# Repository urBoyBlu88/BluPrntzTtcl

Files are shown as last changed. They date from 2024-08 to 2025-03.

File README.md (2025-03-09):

Check out the new Better Reticles code!

keep in mind, the ESP32 is directley connected to the pins of the LCD
The tft settings will have to be edited to match your wiring!
remeber all you need to change is 

CS = 
DC = 
RES =

and then in the setup:
SPI.begin(SDA,MISO,SCL,CS)

after changing those things to match your connections you should be golden :) 

//////////////////////////////////////////////////////////////
Plug into your computer USB 3.0 - must be a usb3.0 port

Your ESP32 C3 will not connect to your Computer Immediatley you MUST PUT IT INTO BOOT MODE!

HOW TO PUT INTO BOOT MODE

Hold the RESET button, then press the BOOT button, now both button held down; let go of Reset and then after 1 more second let go of Boot and you should connect.

Download the Code Zip folder

unzip that folder

run the .ino file

it will ask you to make a new folder for it

hit yes/ok

now select your board - set it to a esp32 c3 dev module

upload

////IMPORTANT/////

-IF your ESP32 C3 will not connect to your Computer, hold the RESET button, and push the BOOT down at the same time, let go of Reset and then let go of Boot after another second and you should connect.

/////////////////1/24/25 UPDATE/////////////////////

Check out the new XiaoSeedStudioFossDot file if you want to only have a single port for charging and programming! or you accidently got a seed studio esp32c3!

//////////////////OLED v2 UGLY////////////////////////////////////

COMPONENTS
1.	ESP32-C3 with 0.42 OLED
a.	Link for product
2.	Lipo Battery Rechargeable Lithium Polymer ion Battery 
a.	I like to buy the gas station disposable vapes, and steal the battery out of it
3.	Switch 3 prong
4.	Button – button cap
5.	Flash light led and reflector
6.	Battery Charging Board with Battery Protection BMS 5V Micro USB 1A 186 50 Charge Module
7.	Connection wires

3D PRINTING STUFF
1.	Elagoo PLA+
2.	Top half –
 
3.	Rail Connection base left side clamp –
 
4.	right side clamp –

HARDWARE
1.	4  m2 screws
2.	2 bolts and nuts m4
3.	USBC cable 
4.	Botton cap – you can print this too

SOFTWARE
1.	Arduino IDE
a.	Libraries for ESP32-C3 dev module
b.	U8g2lib
2.	https://lopaka.app/ - this is to make graphics 
3.	Slicer software

STEP ONE: PRINT IT
Bring the STL files into your preferred slicer program, I Used Anycubic Slicer as I have a Anycubic Kobra 3 printer. 

My Print Setting:
60 to 100% infill – this is up to you, more infill = more durability. 
Normal PLA+ settings for your printer
I use organic supports from build plate only
Print orientation 
-leave it as it is in the STL it should be in the proper rotation see images for reference. You can change the base/rail connection orientation, as I have not yet found the best one. 

STEP TWO: ASSEMBLY
I like to place my components in the frame without securing them. 

From here I measure my wires to cut proper lengths and so as not to have too much wire inside. 

Follow this Diagram  

Rechargeable battery :
Solder the batter + to recharge board bat+

Solder battery – to recharge board bat-

Battery power to ESP32-C3:
Solder wire to out + on the recharge board 

Solder the other side of that wire to the left side of the Switch
Solder a wire to the middle prong of the Switch
The other side of the middle prong wire, Solder to the BAT pin on the esp32 

Solder wire to the Out- on the recharge board

Solder a black wire onto the Grnd Pin on the Esp32. This is so we can add multiple connections to the grnd pin. 

Slice the black wire so you have 3 open connection points

Solder the other side of that wire to the black grnd wire at the connection point closest to the ESP32

Now it’s a rechargeable battery powered esp32!

Lets Add a button and a Flashlight!
First lets add a wire coming off the 3V pin on the ESP32. This will allow for multiple connection points.

Next, solder a 10kOhm resistor to one pin on your button. 
Solder a wire to the other side of the resistor.
Solder the other side of the resistor wire to the second connection on the ground wire. 
Solder a wire on the same button pin as the resistor
solder that wire to pin 1 on the ESP 32
Now, the pin diagonally across from the button pin the resistor and wire are connected to…
Solder a red wire
Connect the other side of the red wire to one connection point of the 3.3V pin
Voila you have a button on a rechargeable Esp32 c3

If you want a flashlight follow this, if not skip ahead to the next section.
Flashlight;
This one about the same as the button. If you don’t have a flashlight light with a little board connected to it, just add a 10kohm resistor to your led + leg
Connect a red wire to the + pin, usually the one in the middle of the board
Connect the other side to a connection point of the Pin 7
Now connect the – pin of the led to a black wire, usually the post on a board or the outside circle.
Connect the other side to a connection point on the ground wire on the esp32.
Now you have a flashlight that will be able to be toggled on and off via Bluetooth

All right that’s everything Time to Code!

/////////////////////////////////////FOSS DOT RGB/////////////////////////////////////////////////////
FOSS DOT Optics Operation
 
Hi there!
Thank you for joining the Blue Printz Tactical Family!
As the new owner of a FOSS Dot Optic I wanted to give you some basic instructions!
Charging: remove the slip on ring on the back. Once removed, you can now lift out the main carriage, make sure to line the battery back up with it slot when reinserting! On the exposed bottom of the carriage are 2 usb ports, one on the blue board and one on the black esp32. Connect to the blue tp4056 to charge, if you so desire to reprogram, plug in to the esp32 and inser the usb cabe to your computer. 

Reprogram:
I used Arduino IDE so it should be easy enough for you as well. 
https://github.com/urBoyBlu88/BluPrntzTtcl/blob/main/ColorFOSSDOT.ino

Here is the code, id recommend swapping the images that are green. Blue and white images work best in all light conditions. I’m still testing other color configures.
You can download my image .h files from this same git repo.

download this board manager, same version is probably best.

and the adafruit st7735 and st7789 lib

the correct board to select is esp32 c3 dev board
 
here is my upload config

Bluetooth Windage and Elevation:
On your phone, Download this app,

https://play.google.com/store/apps/details?id=com.zhctwh.ble_tester 
With your Foss Dot powered ON. Bluetooth on you phone turned ON, and location on your phone turned ON; open the app and hit the scan button at the bottom. Search for “UglyOptic” and select it. 
Then click the last option on the list that says “service” and has a bunch of letters and numbers.

Next tap in the write area to enter text. Set the check box from hex -> ASCII. You want it to be ASCII.

Here are your codes to enter for W&E(I hope they are as simple as I think they are!)
!* all entered letter should be lowercase *!
l – enter lowercase ‘L’, your reticle should shift left 
r – enter lowercase ‘R’, your reticle should shift right
u – enter lowercase ‘U’, your reticle should shift up
d – enter lowercase ‘D’, your reticle should move down
m – enter lowercase ‘M’ your reticle should center on screen. 

Lenses are removable if you wish to change the view of the reticle on the lens. OR simply if you need to replace the lens. Here is the lens used: lens.

If you have any questions or concerns at all, please do not hesitate to reach out! We are always happy to help however we can here at Blue Printz Tactical!
Thanks for your Support!
Check back on the site or on reddit for new updates and innovations!
Warm Regards,
Blue Printz Tactical
blooperspecive@gmail.com

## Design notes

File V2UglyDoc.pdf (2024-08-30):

# V2-UGLY

### COMPONENTS

1. ESP32-C3 with 0.42 OLED
a. Link for product
2. Lipo Battery Rechargeable Lithium Polymer ion Battery Pack
a. I like to buy the gas station disposable vapes, and steal the battery out of it
b. Or, link
3. Switch 3 prong
4. Button – button cap
5. Flash light led and reflector
6. Battery Charging Board with Battery Protection BMS 5V Micro USB 1A 186 50 Charge Module (https://www.amazon.com/Mudder-Pieces-Charging-Battery-Protection/dp/B087Q915LF)
7. Connection wires

### 3D PRINTING STUFF

1. Elagoo PLA+
2. Top half –
3. Rail Connection base left side clamp –
4. right side clamp -

### HARDWARE

1. 4 m2 screws
2. 2 bolts and nuts m4
3. USBC cable
4. Botton cap – you can print this too

### SOFTWARE

1. Arduino IDE
a. Libraries for ESP32-C3 dev module
b. U8g2lib
2. https://lopaka.app/ - this is to make graphics
3. Slicer software

# V2-UGLY

### STEP ONE: PRINT IT

Bring the STL files into your preferred slicer program, I Used Anycubic Slicer as I have a Anycubic Kobra 3 printer.

My Print Setting:
60 to 100% infill – this is up to you, more infill = more durability. Normal PLA+ settings for your printer
I use organic supports from build plate only
Print orientation
-leave it as it is in the STL it should be in the proper rotation see images for reference.

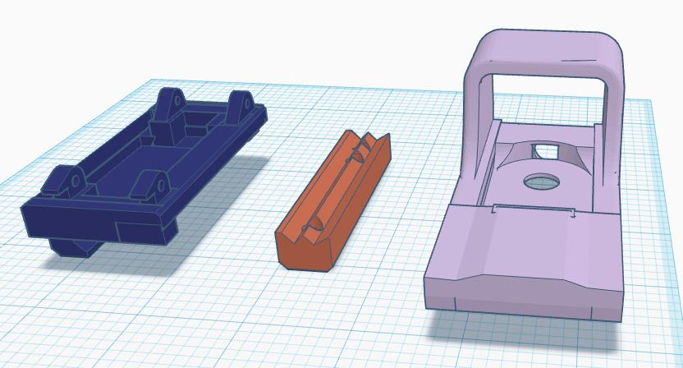
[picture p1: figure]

### STEP TWO: ASSEMBLY

I like to place my components in the frame without securing them.

From here I measure my wires to cut proper lengths and so as not to have too much wire inside.

# V2-UGLY

Follow this Diagram

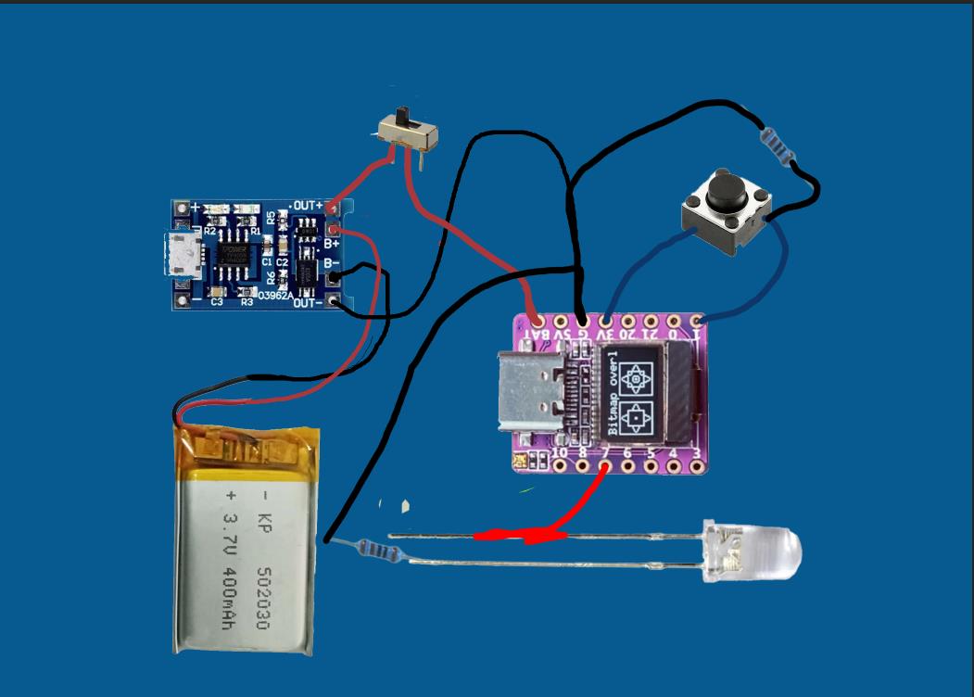
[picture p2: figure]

Rechargeable battery :
Solder the batter + to recharge board bat+

Solder battery – to recharge board bat-

Battery power to ESP32-C3:
Solder wire to out + on the recharge board

Solder the other side of that wire to the left side of the Switch
Solder a wire to the middle prong of the Switch
The other side of the middle prong wire, Solder to the BAT pin on the esp32

# V2-UGLY

Solder wire to the Out- on the recharge board

Solder a black wire onto the Grnd Pin on the Esp32. This is so we can add multiple connections to the grnd pin.

Slice the black wire so you have 3 open connection points

Solder the other side of that wire to the black grnd wire at the connection point closest to the ESP32

Now it’s a rechargeable battery powered esp32!

Lets Add a button and a Flashlight!
First lets add a wire coming off the 3V pin on the ESP32. This will allow for multiple connection points.

Next, solder a 10kOhm resistor to one pin on your button.
Solder a wire to the other side of the resistor.
Solder the other side of the resistor wire to the second connection on the ground wire. Solder a wire on the same button pin as the resistor
solder that wire to pin 1 on the ESP 32
Now, the pin diagonally across from the button pin the resistor and wire are connected to… Solder a red wire
Connect the other side of the red wire to one connection point of the 3.3V pin
Voila you have a button on a rechargeable Esp32 c3

If you want a flashlight follow this, if not skip ahead to the next section. Flashlight;

# V2-UGLY

This one about the same as the button. If you don’t have a flashlight light with a little board connected to it, just add a 10kohm resistor to your led + leg
Connect a red wire to the + pin, usually the one in the middle of the board
Connect the other side to a connection point of the Pin 7
Now connect the – pin of the led to a black wire, usually the post on a board or the outside circle. Connect the other side to a connection point on the ground wire on the esp32.
Now you have a flashlight that will be able to be toggled on and off via Bluetooth

All right that’s everything Time to Code!

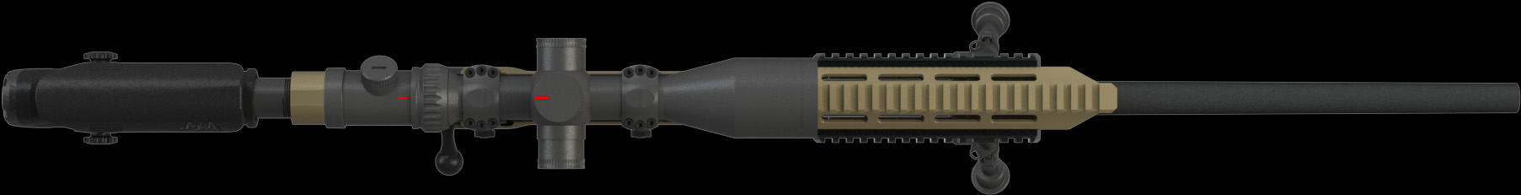
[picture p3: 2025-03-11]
3DViewerFiles/playerRifle.jpg

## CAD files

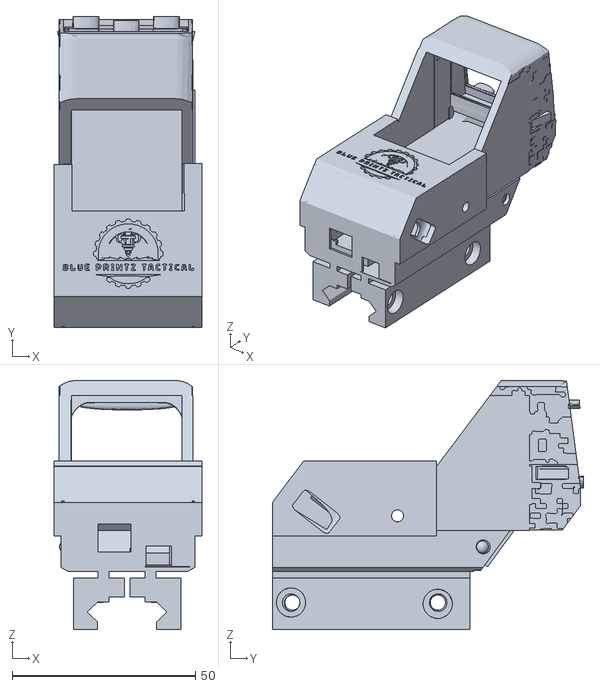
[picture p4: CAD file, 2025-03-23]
3DViewerFiles/FullBuild.stl
40.3 x 84.9 x 67.9

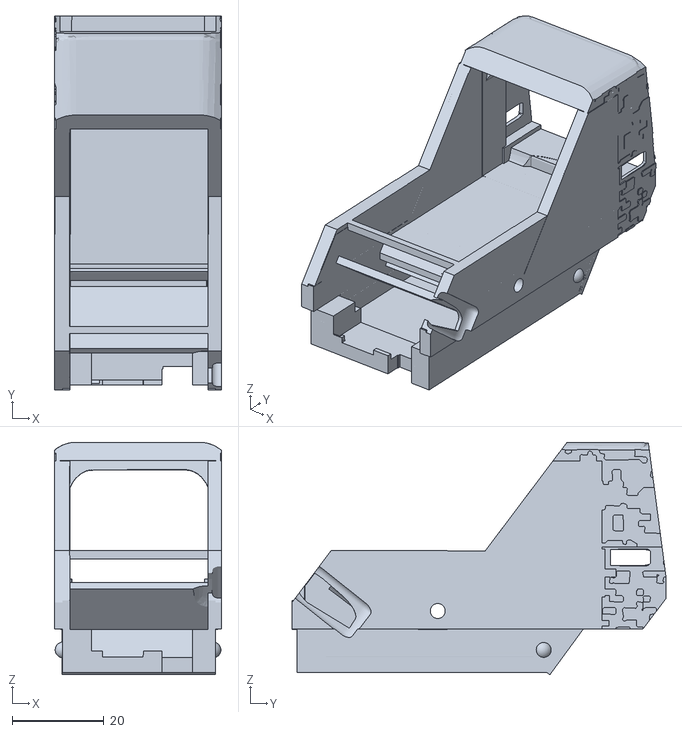
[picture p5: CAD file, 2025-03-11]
3DViewerFiles/FOSSPROMainBod.stl
36.5 x 81.7 x 50.8

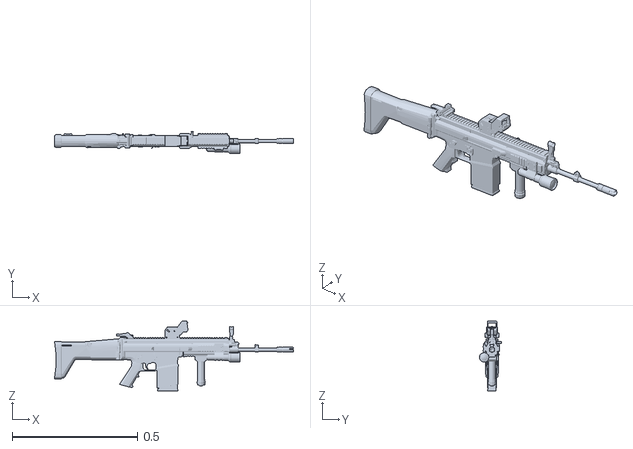
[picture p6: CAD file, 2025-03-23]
3DViewerFiles/rifleWFoss.stl
0.953 x 0.0889 x 0.279

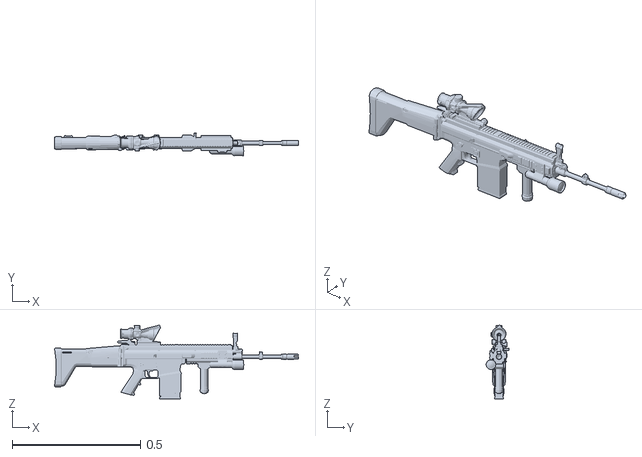
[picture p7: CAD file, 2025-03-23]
3DViewerFiles/rifle.stl
0.953 x 0.0889 x 0.288

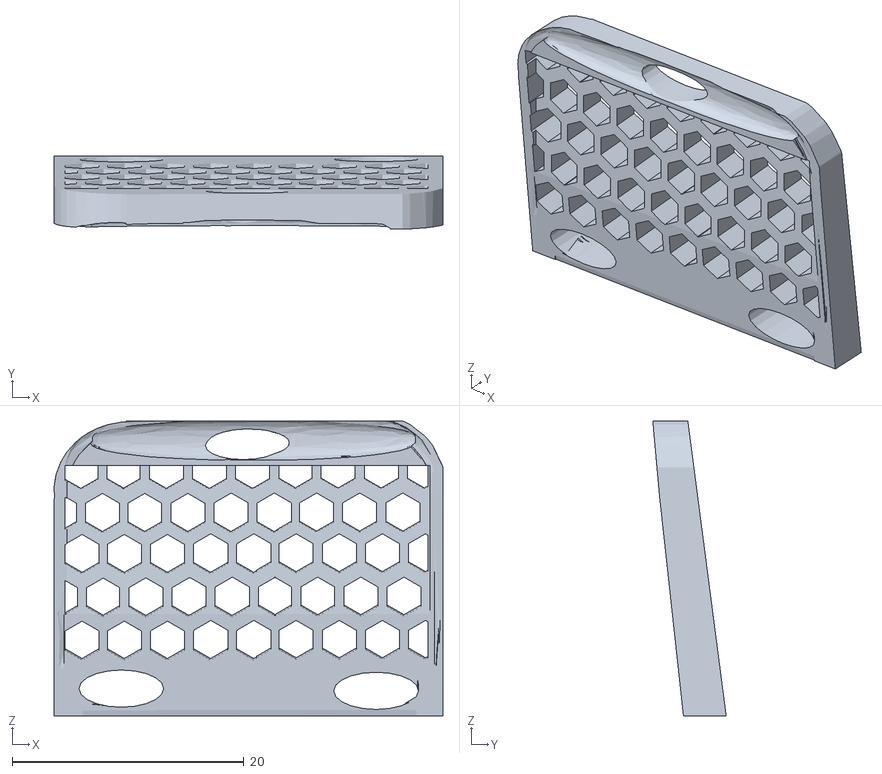
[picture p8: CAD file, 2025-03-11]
3DViewerFiles/FOSSPROKillFlash.stl
33.5 x 6.33 x 25.4

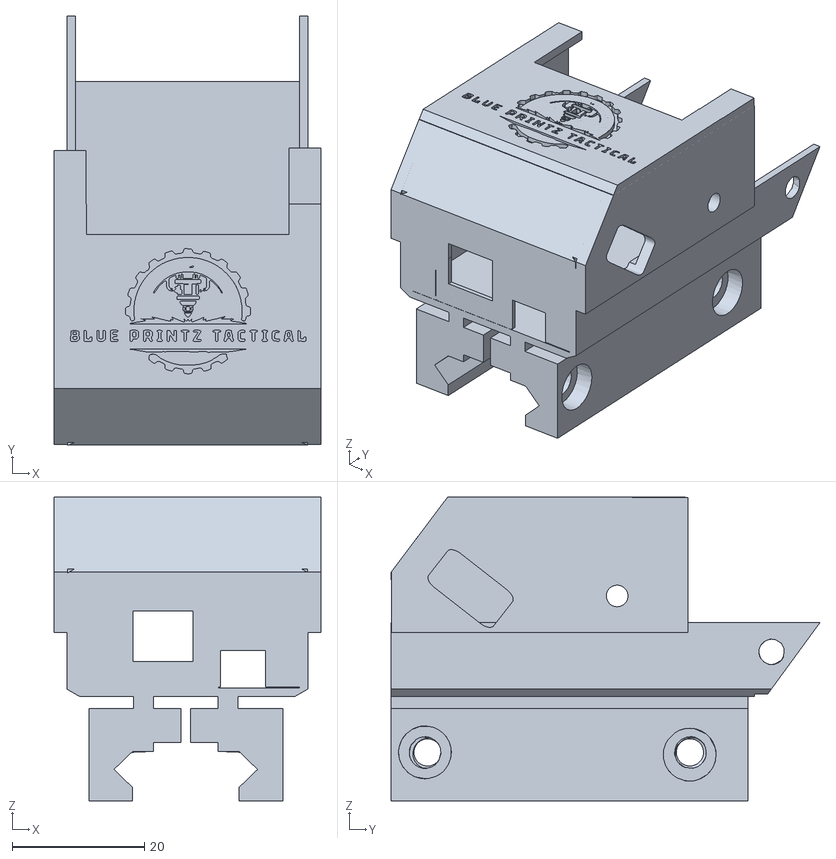
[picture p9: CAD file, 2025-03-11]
3DViewerFiles/FOSSDOTPRORailAttach.stl
40.3 x 64.8 x 45.9

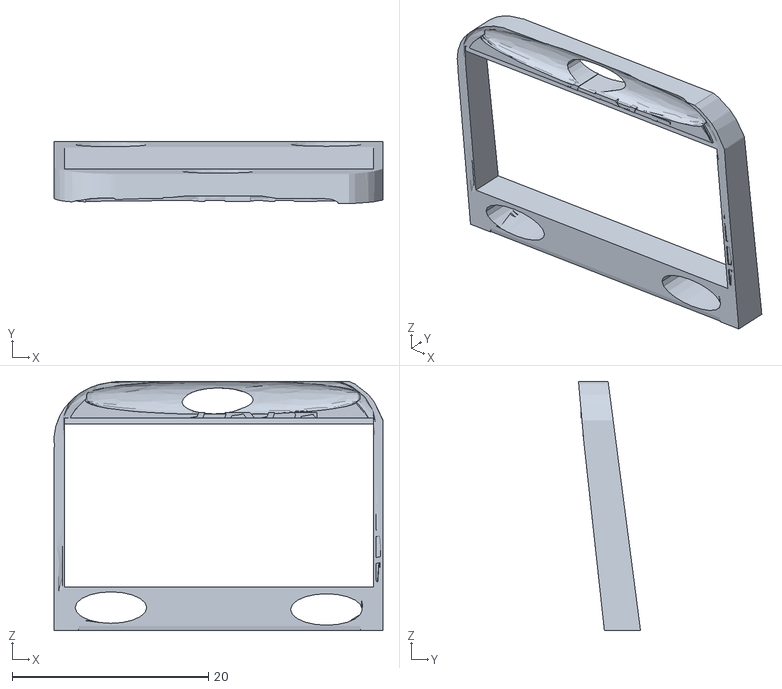
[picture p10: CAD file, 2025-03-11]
3DViewerFiles/FOSSPROSunGlassLens.stl
33.5 x 6.33 x 25.4

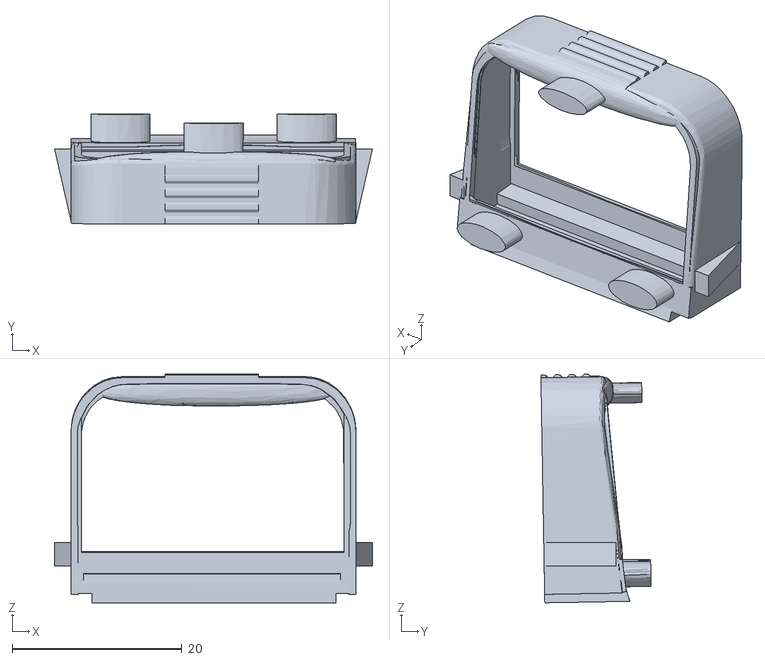
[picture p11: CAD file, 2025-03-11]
3DViewerFiles/FOSSPROLensHolder.stl
37.5 x 13.0 x 27.0

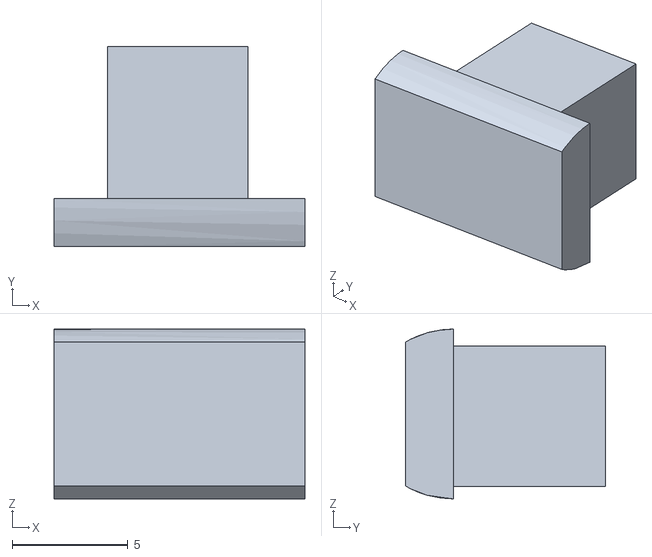
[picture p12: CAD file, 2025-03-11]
3DViewerFiles/FOSSPROSwitchCover.stl
10.8 x 8.65 x 7.33

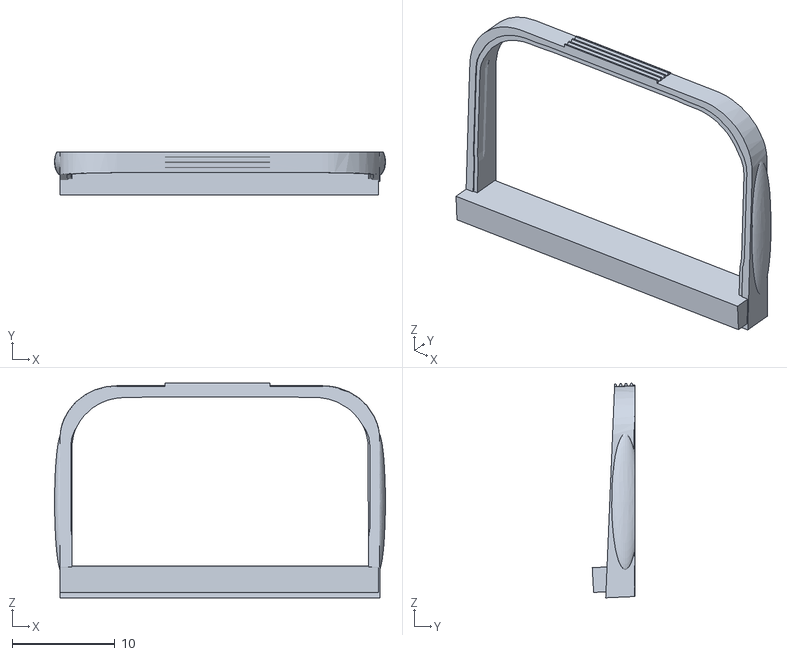
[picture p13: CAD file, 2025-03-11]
3DViewerFiles/FOSSPROLensHolderInsert.stl
32.2 x 4.14 x 20.9

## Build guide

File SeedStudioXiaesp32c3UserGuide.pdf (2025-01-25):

FOSS DOT USER GUIDE

XIAO SEED STUDIO ESP32C3 edition

This document will teach you how to use your FOSS Dot

Welcome to the Blue Printz Tactical Family!

You have just received your FOSS Dot and are ready to charge it up and maybe even add some of your own reticles!

This guide is specific to the Seed Studio version of the logic board.

CHARGING YOUR FOSS DOT
- First remove the Carriage from the foss dot main body. This is done by removing the retention ring on the back and then pushing the carriage up and out.

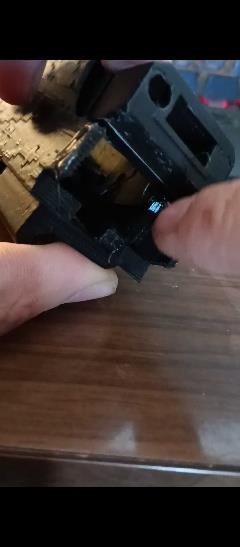
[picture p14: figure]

•

- Next tilt the screen downward until you can see the usb port. •

•

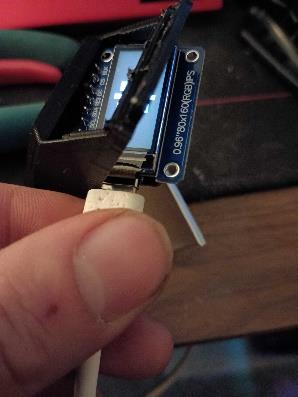
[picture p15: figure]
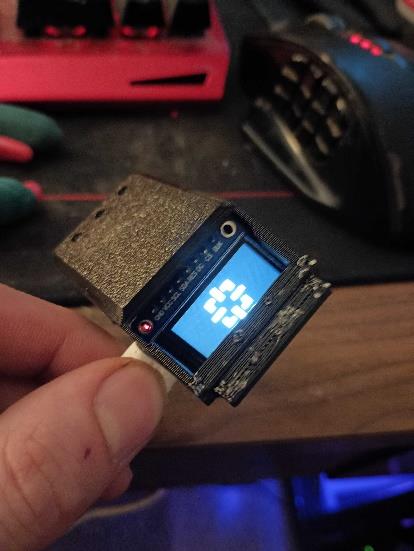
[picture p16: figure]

Insert USBC cable and see the red indicator

•

## ADDING RETICLES: REPORGRAMMING

- The same first steps to remove the carriage and plug it in as to charge it.

I used Arduino IDE so it should be easy enough for you as well.

- If you do not have the Arduino IDE installed do so now -https://www.arduino.cc/en/software

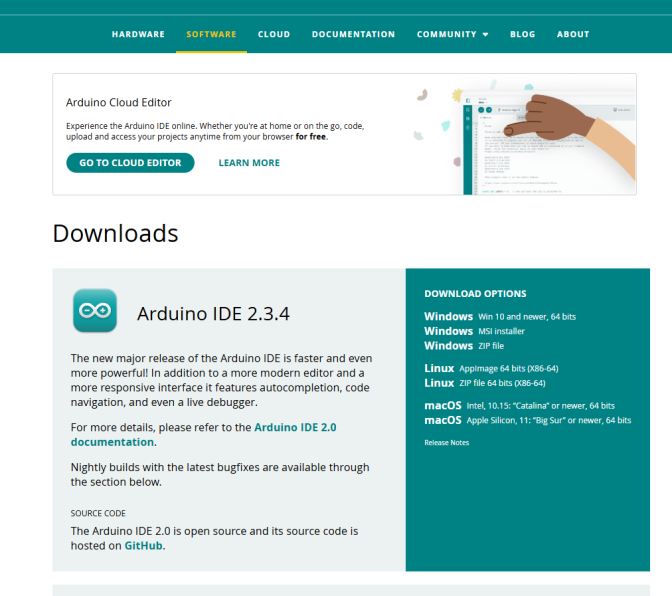
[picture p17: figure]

First get the Program:
https://github.com/urBoyBlu88/BluPrntzTtcl -download the XiaoSeedStudioFossDot ZIP

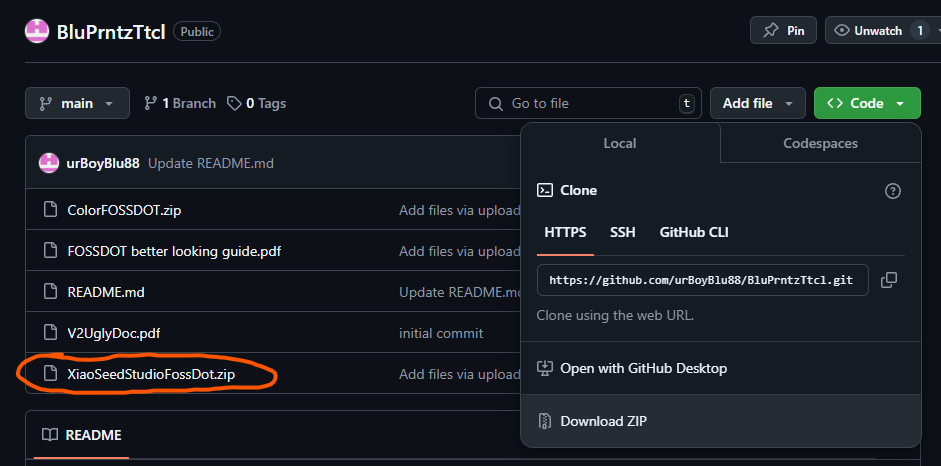
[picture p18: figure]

-Unzip the file in a location you want

-inside the file-
-run the .ino file (should have the Arduino app icon if you have it downloaded)

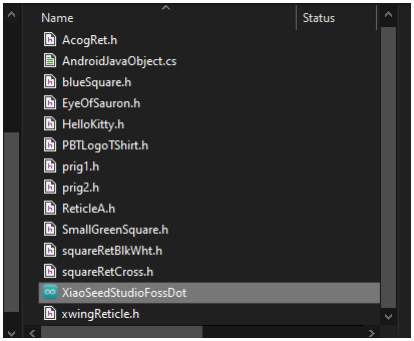
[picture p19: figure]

When you open, it will ask you to save, say yes.

-Getting Setup Inside the Arduino IDE-Download this board manager, updating to the latest version is probably best, mine may be old

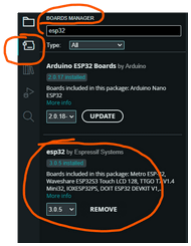
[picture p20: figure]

Add the adafruit st7735 and st7789 lib

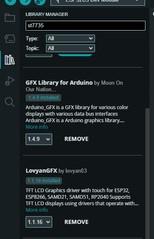
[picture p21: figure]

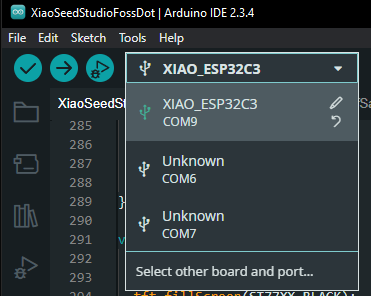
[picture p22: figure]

the correct board to select is XIAO_ESP32C3

– if it says esp32 family device:
- Go to tools on the top left
- Board->ESP32_>Xiao_Esp32C3

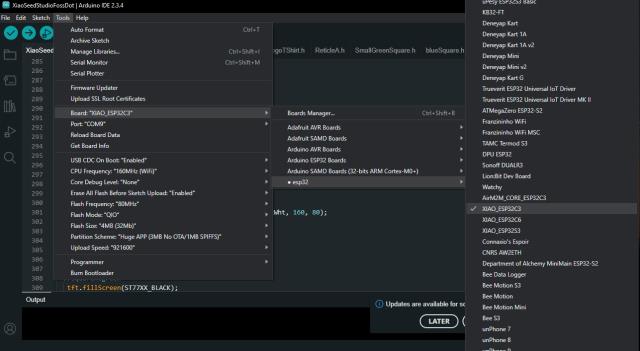
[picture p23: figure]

-Make sure the tool settings are correct-

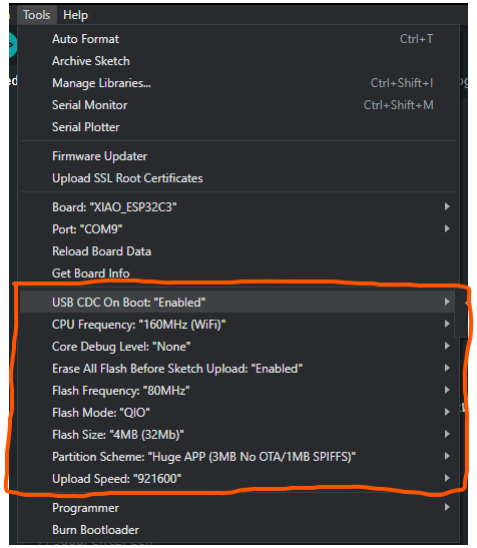
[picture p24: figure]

## UPLOAD THE CODE

- Make sure your device is connected and visible on a com in the Arduino IDE.

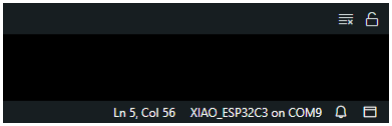
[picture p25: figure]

Once you change the program your ready to press upload and test your work!

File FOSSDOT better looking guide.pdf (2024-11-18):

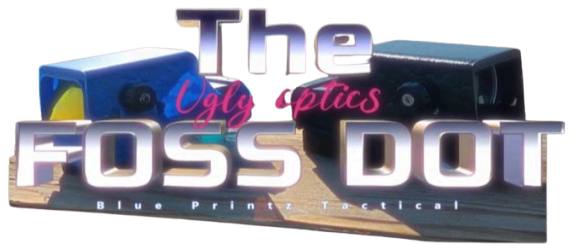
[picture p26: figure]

Seal Enthusiast (https://linktr.ee/SealEnthusiast) presents:

# The FOSS DOT User guide

Original design and user guide by: Blue Printz Tactical (https://blueprintztactical.com/)

# Printing

# Wiring

# More Wiring

# FOSS DOT Optics Operation

## Printing

1.
Use normal temps and settings as you filament provider suggests (I recommend PLA+ for your filament)

2.
Below is the proper orientation of the prints, make sure they match!

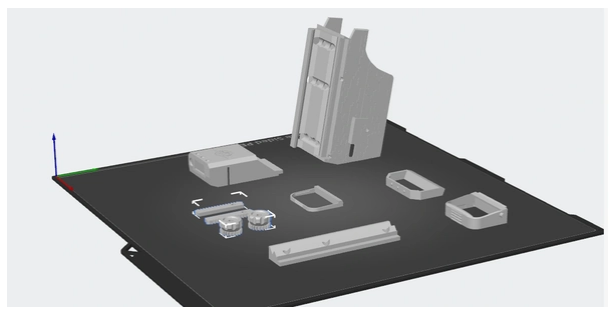
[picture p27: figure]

3.
Start printing!

*THE BOLTS USED FOR THE COGS AND RAIL ATTACHMENT:
6-32 1/2 for the cogs
10-32 1 and 1/2 for rails

## Wiring

ST7735 Wiring

Wiring is simple, follow the esp32 super mini pinout sheet provided for sclk(scl) and mosi(sda). In the code set which pins you want to use for CS,DC, and Reset. Then of course vin goes t0 3.3, and ground to gnd.

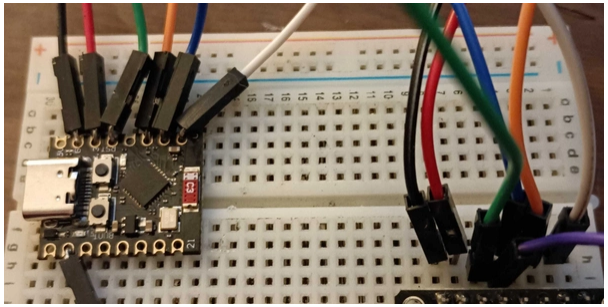
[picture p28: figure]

## More Wiring

From the 5V pin on the esp32, connect a wire to the left or right outside pin of the switch.

Connect a wire between the middle pin of the switch and the Out+ side of the TP4056.

From the Gnd pin on the TP4056 connect a wire to the ground wire on the esp32.connect the battery positive wire(red) to the B+ on the TP4056.

Connect the battery negative wire(black) to the B- on the TP4056.

For the button connect a wire to the 3.3v line. Attach this wire to one pin on the button.

Connect a wire from pin 21 on the ESP32 to the pin diagonally opposite, or the one next to the power pin, on the button.

Connect your pin on the button that is connected to pin 21, with a 10k ohm resistor.Attach the other side of the resistor to the ground wire off of the esp32.

Optionally if you would only like to use 1 single port for charging and data, connect a wire from the 5v pin on the esp32 and wire it to the +in next to the usb port on the tp4056. then using the esp32 port will charge the battery with the tp4056.

Time to Code!

Keep in mind you may need to initialize a different tft if your colors are inverted!

https://github.com/urBoyBlu88/BluPrntzTtcl/blob/main/C olorFOSSDOT.ino (https://github.com/urBoyBlu88/BluPrntzTtcl/blob/main/ColorFOSSDOT.ino)

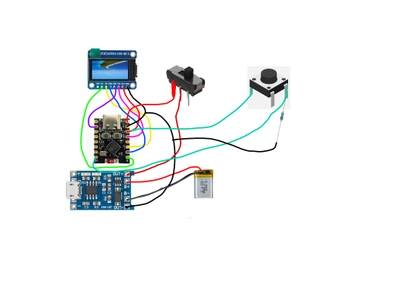
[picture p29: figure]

## FOSS DOT Optics Operation

Charging

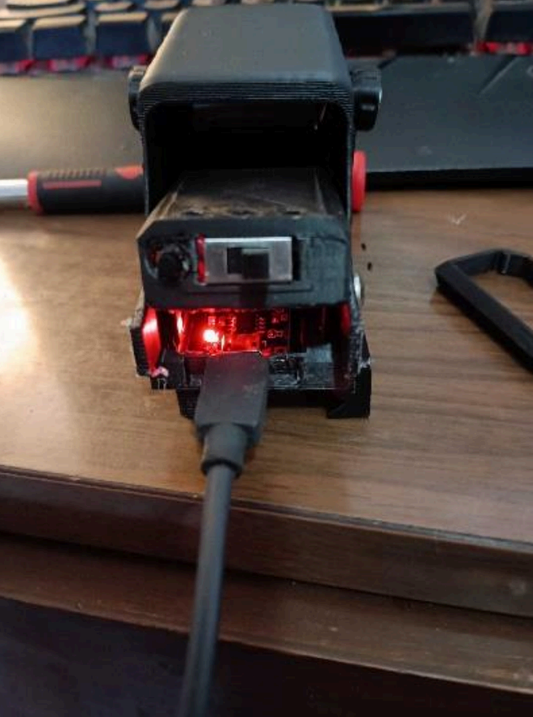
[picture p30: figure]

Remove the slip on the ring on the back. Once removed, you can now lift out the main carriage, make sure to line the battery back up with its slot when reinserting! On the exposed bottom of the carriage are 2 usb ports, one on the blue board and one on the black esp32. Connect to the blue tp4056 to charge, if you so desire to reprogram, plug in to the esp32 and insert the usb cable to your computer.

Reprograming

I used Arduino IDE so it should be easy enough for you as well.

https://github.com/urBoyBlu88/BluPrntzTtcl/blob/main/ColorFOSSDOT.ino (https://github.com/urBoyBlu88/BluPrntzTtcl/blob/main/ColorFOSSDOT.ino)

Here is the code, I would recommend swapping the images that are green. Blue and white images work best in all light conditions. I’m still testing other color configurations. You can download my image .h files from this same git repo. download this board manager, the same version is probably best.

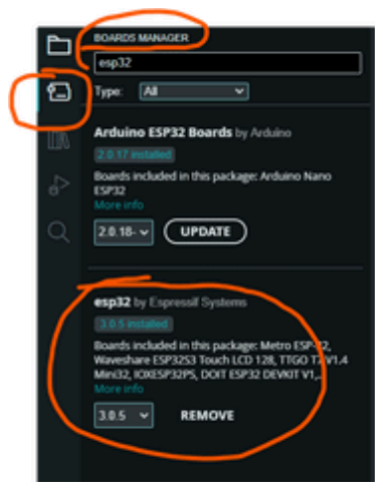
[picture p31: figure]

Next add the adafruit st7735 and st7789 lib

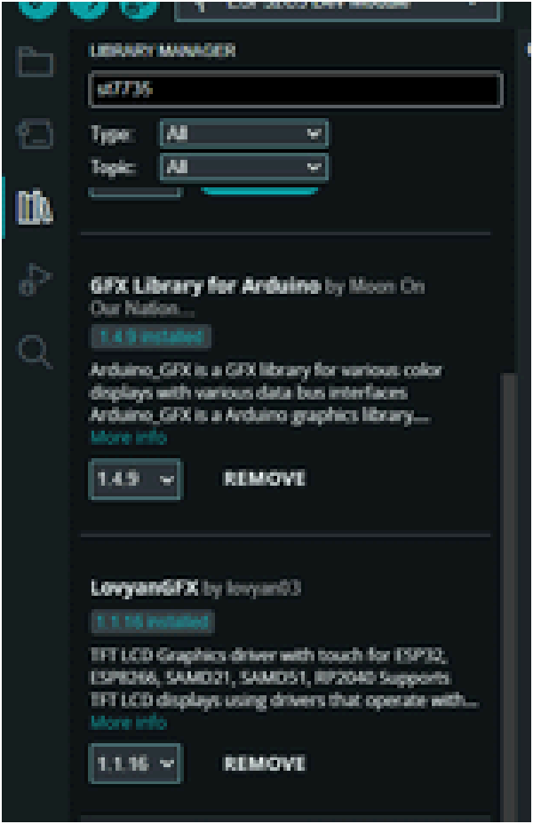
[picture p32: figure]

The correct board to select is the esp32 c3 dev board

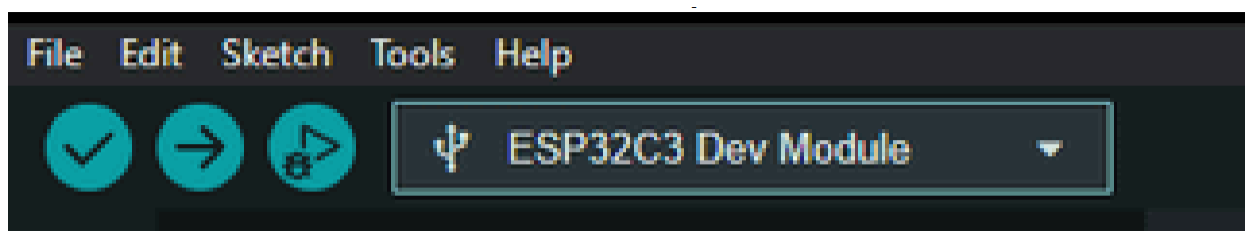
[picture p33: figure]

Below is a example upload config

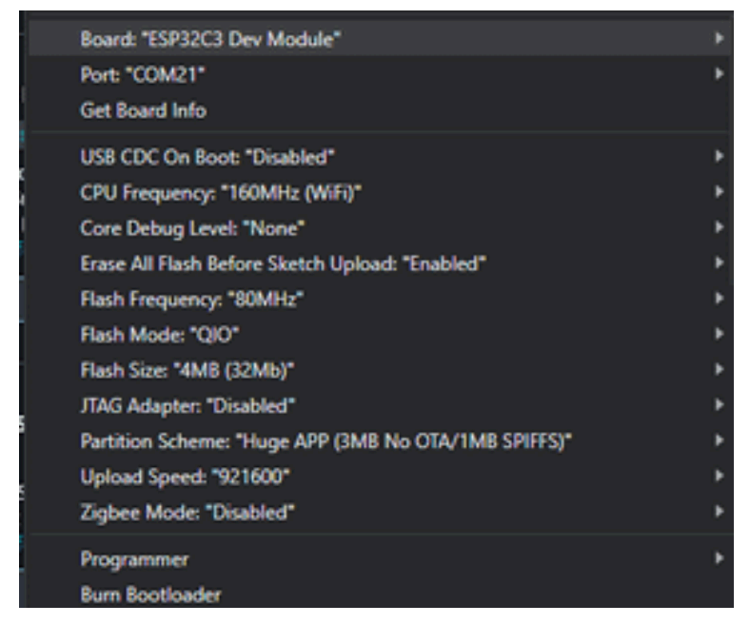
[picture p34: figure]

Bluetooth Windage and Elevation

On your phone, Download this app,

https://play.google.com/store/apps/details?id=com.zhctwh.ble_tester (https://play.google.com/store/apps/details?id=com.zhctwh.ble_tester)

With your Foss Dot powered ON. Bluetooth on your phone turned ON, and location on your phone turned ON; open the app and hit the scan button at the bottom.

Search for “UglyOptic” and select it. Then click the last option on the list that says “service” and has a bunch of letters and numbers.

Next tap in the write area to enter text. Set the check box from hex -> ASCII. You want it to be ASCII.

Here are your codes to enter for W&E on the (I hope they are as simple as I think they are!)

!* all entered letter should be lowercase *!

l – enter lowercase ‘L’

, your reticle should shift left

r – enter lowercase ‘R’

, your reticle should shift right

u – enter lowercase ‘U’

, your reticle should shift up

d – enter lowercase ‘D’

, your reticle should
move down

m – enter lowercase ‘M’ your reticle should center on screen.

Lens info

The Lens Used is Length 34mm Width 24mm Thickness 2.74mm Special-shaped beam splitting mirror lens.

Lenses are removable if you wish to change the view of the reticle on the lens.

OR simply if you need to replace the lens.

(The lens used) (https://www.aliexpress.us/item/3256807149344663.html)

(From alibaba (https://www.youtube.com/watch?v=W84gyW6-Ph4) with love)

If you have any questions or concerns at all, please do not hesitate to reach out!

We are always happy to help however we can here at Blue Printz Tactical!

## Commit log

2024-10-10 Add files via upload
    RGB 0.96 inch lcd version of the UGLY optic changing reticle code, 1x button , BLE
2025-01-25 Add files via upload
    Now you can use a seed studio esp32 to make your foss dot!
2025-02-07 FOSS Dot PCB Design
    I created a PCB for the FOSS Dot so it would be easier to make
2025-03-09 New Optimized Reticles!
    better size for maximizing parallax with the specific lens shape, that we use.
